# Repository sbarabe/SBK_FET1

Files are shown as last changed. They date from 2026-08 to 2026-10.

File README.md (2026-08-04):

# SBK_FET1 | MOSFET Module

<h3 align="center">SBK_NFET1 — N-Channel Module</h3>

<p align="center">
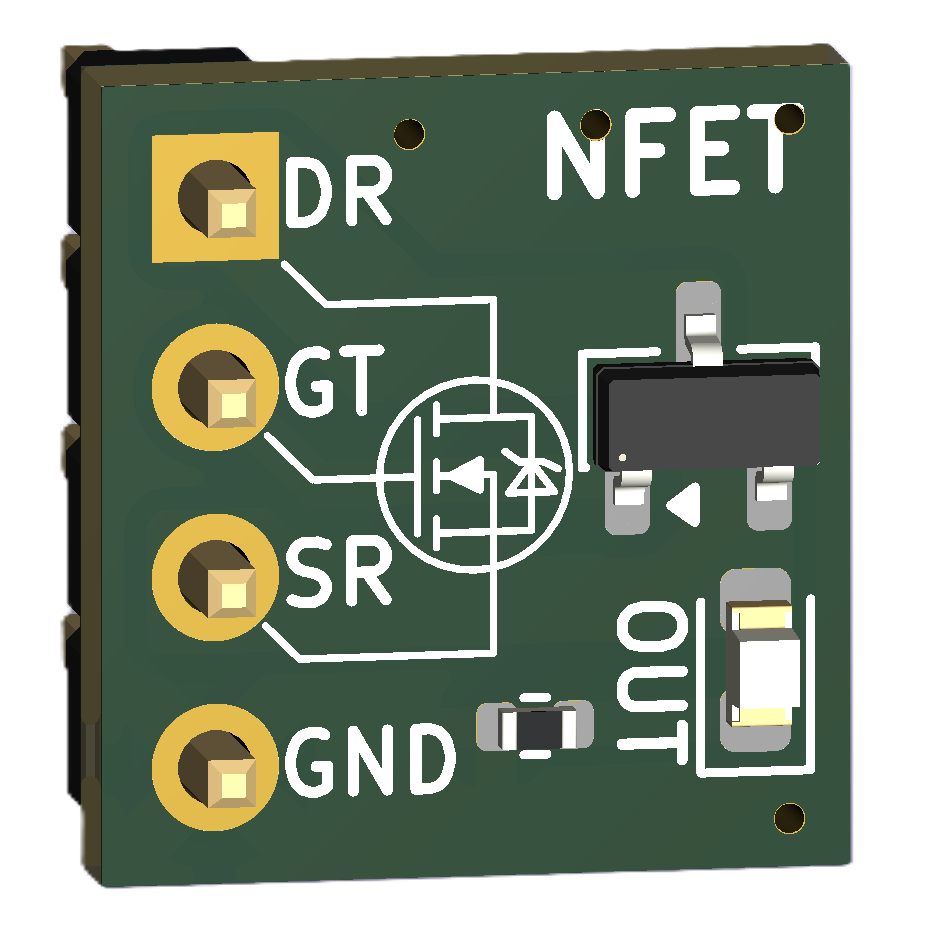
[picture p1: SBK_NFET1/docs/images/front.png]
Front
  
  &nbsp;&nbsp;&nbsp;
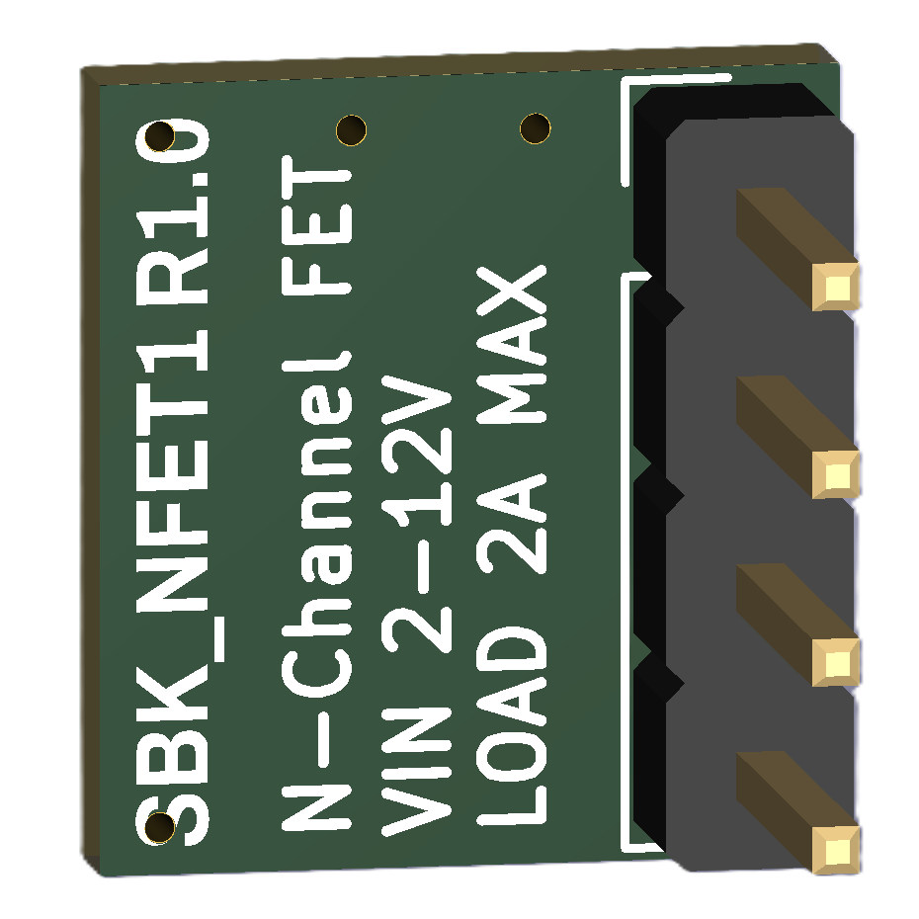
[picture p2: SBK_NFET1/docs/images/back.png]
Back
  
</p>

<p align="center">
  <b>NFET Front</b> &nbsp;&nbsp;&nbsp;&nbsp;&nbsp;&nbsp;&nbsp;&nbsp;&nbsp;&nbsp;&nbsp;&nbsp;&nbsp;&nbsp;&nbsp;&nbsp;&nbsp;&nbsp;&nbsp;&nbsp;&nbsp;&nbsp;&nbsp;&nbsp;&nbsp;&nbsp;&nbsp;
  <b>NFET Back</b>
</p>

<h3 align="center">SBK_PFET1 — P-Channel Module</h3>

<p align="center">
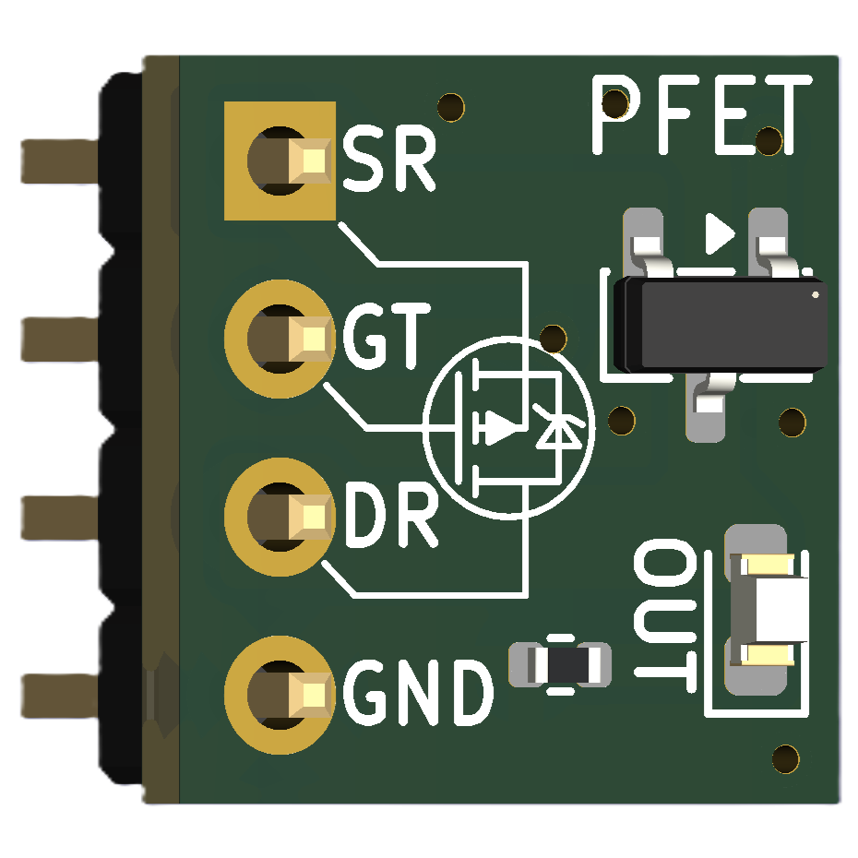
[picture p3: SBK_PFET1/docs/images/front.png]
Front
  
  &nbsp;&nbsp;&nbsp;
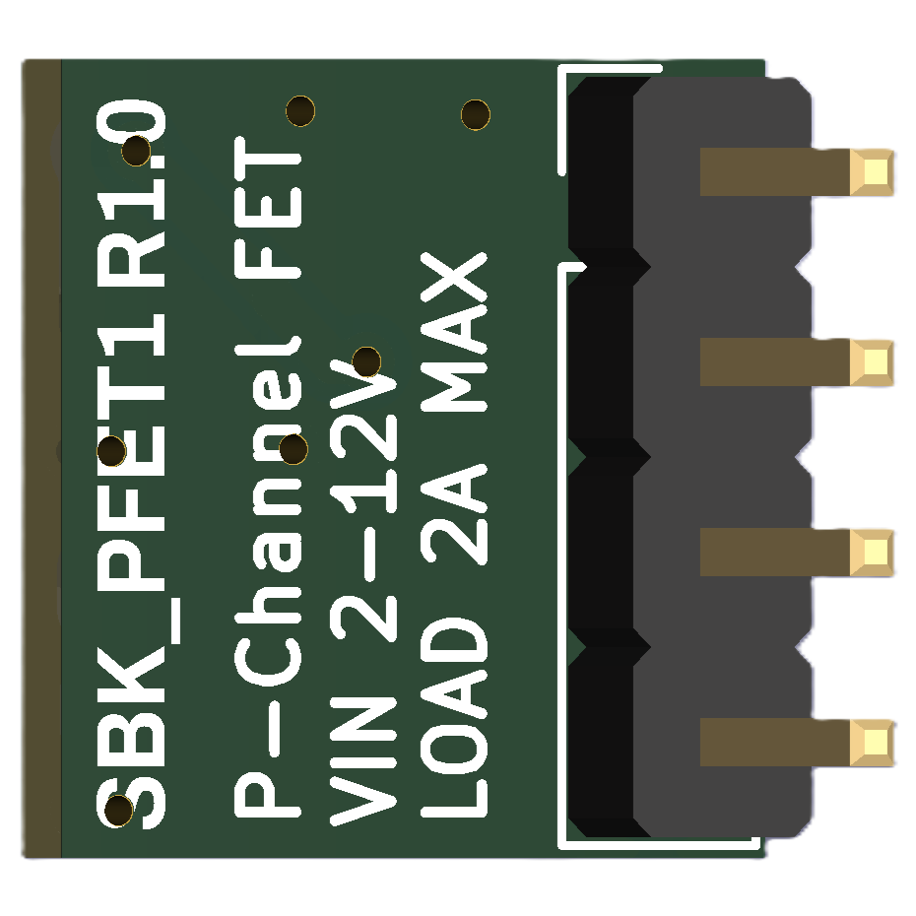
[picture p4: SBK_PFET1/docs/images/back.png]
Back
  
</p>

<p align="center">
  <b>PFET Front</b> &nbsp;&nbsp;&nbsp;&nbsp;&nbsp;&nbsp;&nbsp;&nbsp;&nbsp;&nbsp;&nbsp;&nbsp;&nbsp;&nbsp;&nbsp;&nbsp;&nbsp;&nbsp;&nbsp;&nbsp;&nbsp;&nbsp;&nbsp;&nbsp;&nbsp;&nbsp;&nbsp;
  <b>PFET Back</b>
</p>

---

## Open-source MOSFET module for learning and embedded electronics projects.

SBK_FET1 is a compact educational MOSFET module designed for breadboards, prototyping, and learning electronic switching circuits.

The module is available in both **N-channel** and **P-channel** versions and provides clearly labeled **Drain**, **Gate**, and **Source** connections. An optional output voltage indicator LED can be enabled by connecting the **GND** pin or disabled by leaving it unconnected.

---

## Features

- Available in **N-channel** and **P-channel** versions
- Logic-level MOSFET
- Operating voltage: **2–12 VDC**
- Recommended continuous load: **up to 2 A**
- Clearly labeled Drain, Gate, and Source terminals
- Silkscreen MOSFET symbol showing the intrinsic body diode
- Optional output voltage indicator LED
- LED can be disabled by leaving the GND pin unconnected
- Breadboard-friendly 2.54 mm pin header
- Compact educational module for learning MOSFET operation and switching circuits

---

## Pinout

### SBK_NFET1 Pinout

| Pin | Description |
|---|---|
| **DR** | Drain |
| **GT** | Gate |
| **SR** | Source (**OUT**) |
| **GND** | Optional ground connection for the **OUT** status indicator LED |

### SBK_PFET1 Pinout

| Pin | Description |
|---|---|
| **SR** | Source |
| **GT** | Gate |
| **DR** | Drain (**OUT**) |
| **GND** | Optional ground connection for OUT status  indicator LED |

> **Note:** The **GND** pin is only required to power the status indicator LED. The MOSFET operates normally without it.
>
> The status indicator LED monitors the **OUT** terminal. On **SBK_NFET1**, **OUT** is the **Source** terminal. On **SBK_PFET1**, **OUT** is the **Drain** terminal.

---

## Applications

- LED control
- Relays
- Solenoids
- DC motors
- Low-side switching (N-channel)
- High-side switching (P-channel)
- Logic-controlled loads
- Educational electronics projects
- Breadboard prototyping

---

## Important Notes

- The operating voltage (2–12 V) refers to the switched load voltage.
- The recommended 2 A load rating is based on the module's PCB size and thermal considerations.
- The indicator LED shows that the monitored output node is energized. It does **not** indicate whether the MOSFET is ON or OFF.
- An external flyback diode is required when driving inductive loads such as relays, solenoids, and DC motors.
- Connect the flyback diode across the load, **not** across the MOSFET.

---

## Getting Started

This project is fully open-source hardware. You can:

- Build your own module using the provided KiCad design files.
- Modify the design to suit your application.
- Manufacture your own boards.

### Assembled Modules

If you would prefer fully assembled modules rather than assembling the PCBs yourself, I can provide professionally assembled modules in small batches on demand.

For availability, pricing, or custom quantities, please contact:

📧 **SmartBuildsKits@gmail.com**

Assembled modules are intended for hobbyists, educators, prototypes, and small-scale projects. Availability depends on component stock and production capacity.

---

## Contributing

Suggestions, bug reports, and improvements are welcome.

To report a problem or suggest an improvement, open an Issue. Pull Requests are also welcome for corrections, documentation improvements, and design changes that make the project easier to understand or build.

---

## Support the Project

If this project is useful for learning, teaching, or prototyping, you can support its continued development.

Donations help fund prototype hardware, documentation, educational resources, and future open-source projects.

❤️ [**Support the project through PayPal**](https://paypal.me/sbarab?country.x=CA&locale.x=fr_CA)

Thank you for supporting open-source educational hardware.

---

## Related Projects

- [**SBK_NFET1**](SBK_NFET1) — N-Channel MOSFET Module
- [**SBK_PFET1**](SBK_PFET1) — P-Channel MOSFET Module
- [**SBK_SP1**](https://github.com/sbarabe/SBK_SP1) — Soft Power Switch Module
- [**SBK_RP1**](https://github.com/sbarabe/SBK_RP1) — Reverse Polarity Protection Module
- [**MémoBot**](https://github.com/sbarabe/MemoBot) — Educational memory game using SBK hardware modules

---

## License

This project is released as open-source hardware under the **CERN Open Hardware Licence Version 2 - Permissive (CERN-OHL-P v2)**.

You are free to study, modify, manufacture, and distribute this design under the terms of the license.

See the [LICENSE](LICENSE) file for details.

---

## Design Files

Designed using **KiCad 10**.

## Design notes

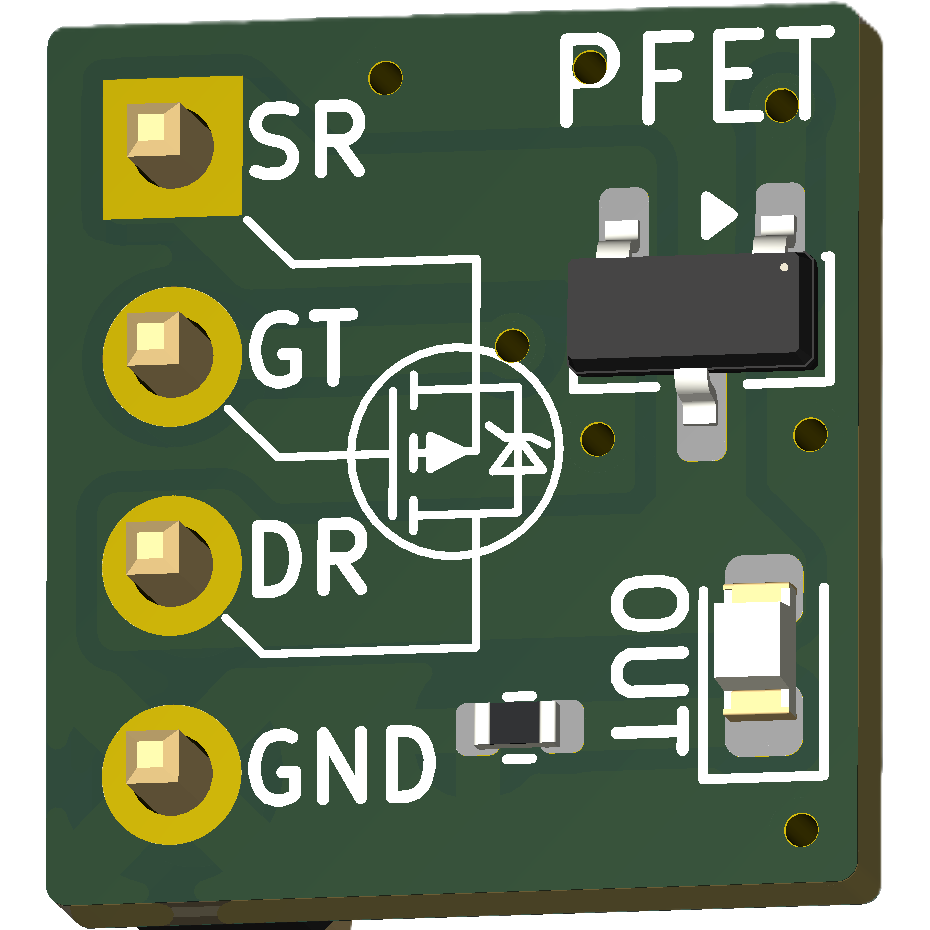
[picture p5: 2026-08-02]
SBK_PFET1/docs/images/module-front.png

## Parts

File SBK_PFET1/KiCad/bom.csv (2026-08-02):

Reference | Qty | Value | Package | Description
D1 | 1 | RED | 0603 | Output status LED
J1 | 1 | 1 x 3 pin header | 2.54 mm | 3-pin header
Q1 | 1 | AO3401A | SOT-23 | P-channel MOSFET
R1 | 1 | 100 kΩ | 0603 | Gate series resistor
R2 | 1 | 15 kΩ | 0402 | Output status LED resistor

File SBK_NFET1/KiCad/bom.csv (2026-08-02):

Reference | Qty | Value | Package | Description
D1 | 1 | RED | 0603 | Output status LED
J1 | 1 | 1 x 4 pin header | 2.54 mm | 4-pin header
Q1 | 1 | AO3400A | SOT-23 | N-channel MOSFET
R2 | 1 | 15 k? | 0402 | Output status LED resistor

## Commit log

2026-08-02 Revise README for MOSFET module details and naming
    Updated README to reflect module name change and added details about N-channel and P-channel versions. Revised features, applications, and important notes sections for clarity.
2026-08-03 Update pin descriptions and notes in README
    Clarified pin descriptions and notes for GND and OUT connections in the README.
2026-08-03 Add SBK_SP1 Soft Power Switch Module link to README
2026-08-04 fritzing symbols added
    [SBK_NFET1.kicad_pcb, SBK_NFET1.kicad_sch, SBK_PFET1.kicad_pcb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]
2026-10-08 PFET1 updates
    [SBK_PFET1.kicad_pcb, SBK_PFET1.kicad_sch]
2026-10-08 NFET1 updates
    [SBK_NFET1.kicad_pcb, SBK_NFET1.kicad_sch]
